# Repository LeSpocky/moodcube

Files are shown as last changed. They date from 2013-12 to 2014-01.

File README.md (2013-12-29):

MoodCube
========

What's This?
------------

With mood39 aka Starterkit from [Netz39](http://www.netz39.de/) and the
[infinity mirror cube](http://www.netz39.de/projekte/infinitiy-mirror-cube/) 
from Frank in mind I designed a mood lamp with five RGB LEDs, three
potentiometers and an ATtiny 24/44 controller.

Circuits
--------

Eagle files for both types of PCB are included. One is the base with the
microcontroller and the potentiometers. VCC is intended to be 5V,
however in the first prototype there's no voltage control circuit on
this pcb, so you have to connect a stabilized power supply.

The other one is a PCB for the LED. Current is hold constant by a simple
constant current circuit per color channel. The connection is simply one
cable per channel plus VCC and GND. uC I/O ports are directly connected
to the color lines.

Housing
-------

The housing in the prototype was 6mm plexiglass milled on a CNC machine.
Holding it together was forgotten in design, but the OpenSCAD files are
added here anyway. Simply glueing them is one solution. You could also
make a base plate or anything else.

LED-PCB Mount
-------------

For the prototype I used a frame construction printed with a 3D printer
and lots of hot melt glue. However this was far from optimal and should
not repeated! Please think up a better solution and let me know!

Part List
---------
/tbd/

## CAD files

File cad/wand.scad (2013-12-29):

// outer wall made from plexiglass to form a cube 150mm×150mm

module wand() {
	linear_extrude( height = 6 ) 
			polygon( points = [ [6,0], [6,25], [0,25], [0,50], [6,50], [6,75], 
				[0,75], [0,100], [6,100], [6,125], [0,125], [0,150], [144,150], 
				[144,125], [150,125], [150,100], [144,100], [144,75], [150,75], 
				[150,50], [144,50], [144,25], [150,25], [150,0] ] );
}

module wand_1() {
	difference() {
		wand();
		translate( [ 65, 5.9, 3 ] ) cube( size = [ 20, 3.2, 4 ] );
		translate ( [ 75, 25, 3 ] ) cylinder( h = 10, r = 4.5, center = true );
	}
}

module wand_2() {
	difference() {
		wand();
		translate( [ 65, 5.9, 3 ] ) cube( size = [ 20, 3.2, 4 ] );
		translate( [ 50, 25, 3 ] ) cylinder( h = 10, r = 5.5, center = true );
		translate( [ 100, 25, 3 ] ) cylinder( h = 10, r = 10.5, center = true );
	}
}

projection( cut = true ) 
	translate ( [ 0, 0, -4 ] ) {
		wand_2();
		translate( [ 155, 0, 0 ] ) wand_1();
		translate( [ 155, 152, 0 ] ) wand_1();
		translate( [ 0, 152, 0 ] ) wand_1();
	}

/* vim: set noet sts=0 ts=4 sw=4 sr: */

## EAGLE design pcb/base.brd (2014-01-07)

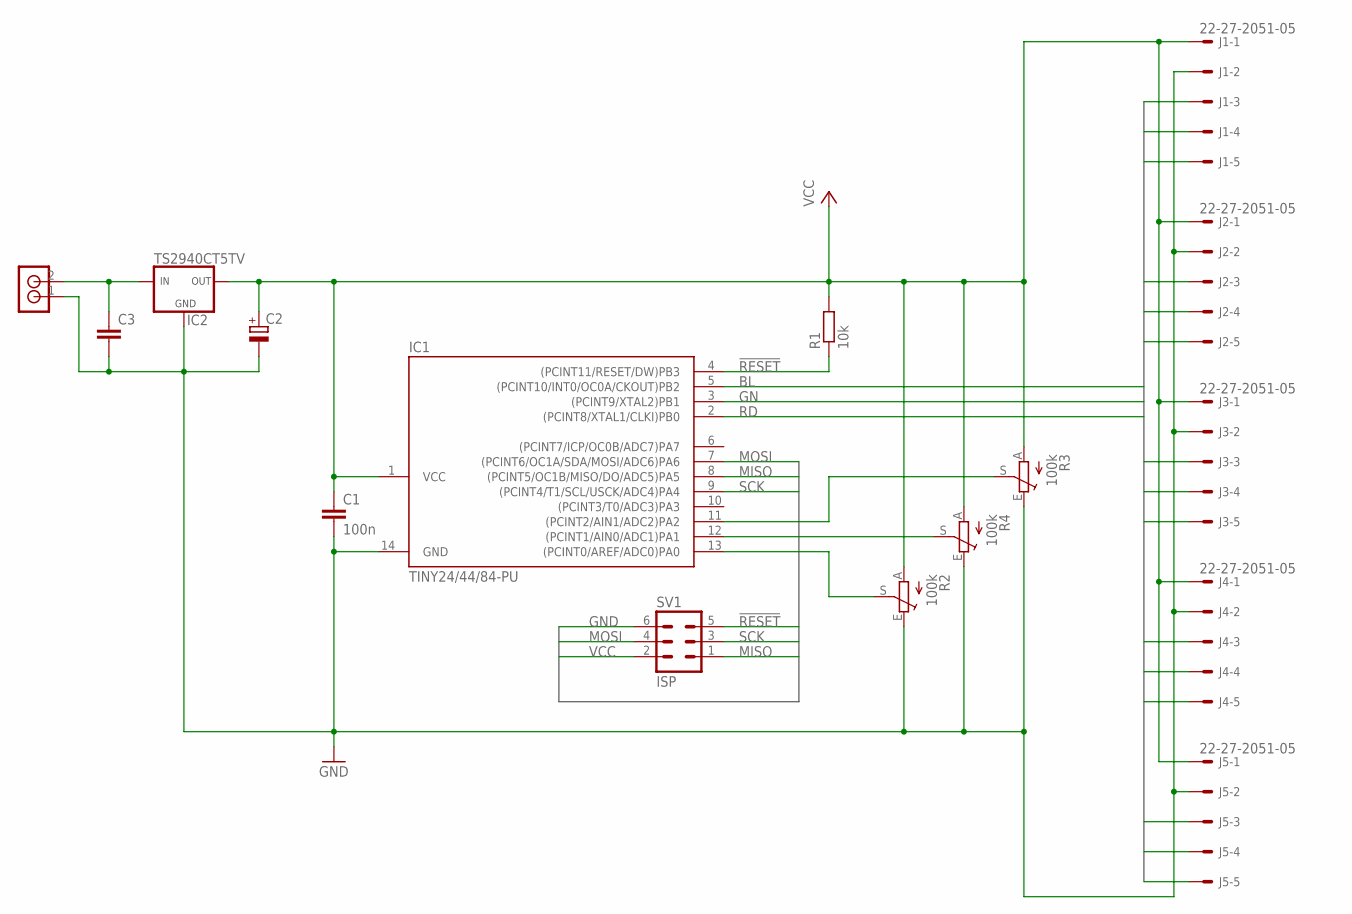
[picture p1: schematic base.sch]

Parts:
C1: 100n; C0805
C2: CPOL-EUE2.5-7; E2,5-7
C3: C-EU025-025X050; C025-025X050
IC1: TINY24/44/84-PU; DIL14
IC2: TS2940CT5TV; TO220V
J1, J2, J3, J4, J5: 22-27-2051-05; 6410-05
R1: 10k; R0805
R2, R3, R4: 100k; CIP20C-6MM
SV1: ISP; ML6
U$9: RIACON_101_2

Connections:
!RESET: IC1.4 ((PCINT11/RESET/DW)PB3), R1.1, SV1.5
BL: IC1.5 ((PCINT10/INT0/OC0A/CKOUT)PB2), J1.5, J2.5, J3.5, J4.5, J5.5
GN: IC1.3 ((PCINT9/XTAL2)PB1), J1.4, J2.4, J3.4, J4.4, J5.4
GND: C1.2, C2.-, C3.2, IC1.14 (GND), IC2.2 (GND), J1.2, J2.2, J3.2, J4.2, J5.2, R2.E, R3.E, R4.E, SV1.6, U$9.1
MISO: IC1.8 ((PCINT5/OC1B/MISO/DO/ADC5)PA5), SV1.1
MOSI: IC1.7 ((PCINT6/OC1A/SDA/MOSI/ADC6)PA6), SV1.4
unnamed: IC1.13 ((PCINT0/AREF/ADC0)PA0), R2.S
unnamed: IC1.12 ((PCINT1/AIN0/ADC1)PA1), R4.S
unnamed: IC1.11 ((PCINT2/AIN1/ADC2)PA2), R3.S
unnamed: C3.1, IC2.1 (IN), U$9.2
RD: IC1.2 ((PCINT8/XTAL1/CLKI)PB0), J1.3, J2.3, J3.3, J4.3, J5.3
SCK: IC1.9 ((PCINT4/T1/SCL/USCK/ADC4)PA4), SV1.3
VCC: C1.1, C2.+, IC1.1 (VCC), IC2.3 (OUT), J1.1, J2.1, J3.1, J4.1, J5.1, R1.2, R2.A, R3.A, R4.A, SV1.2

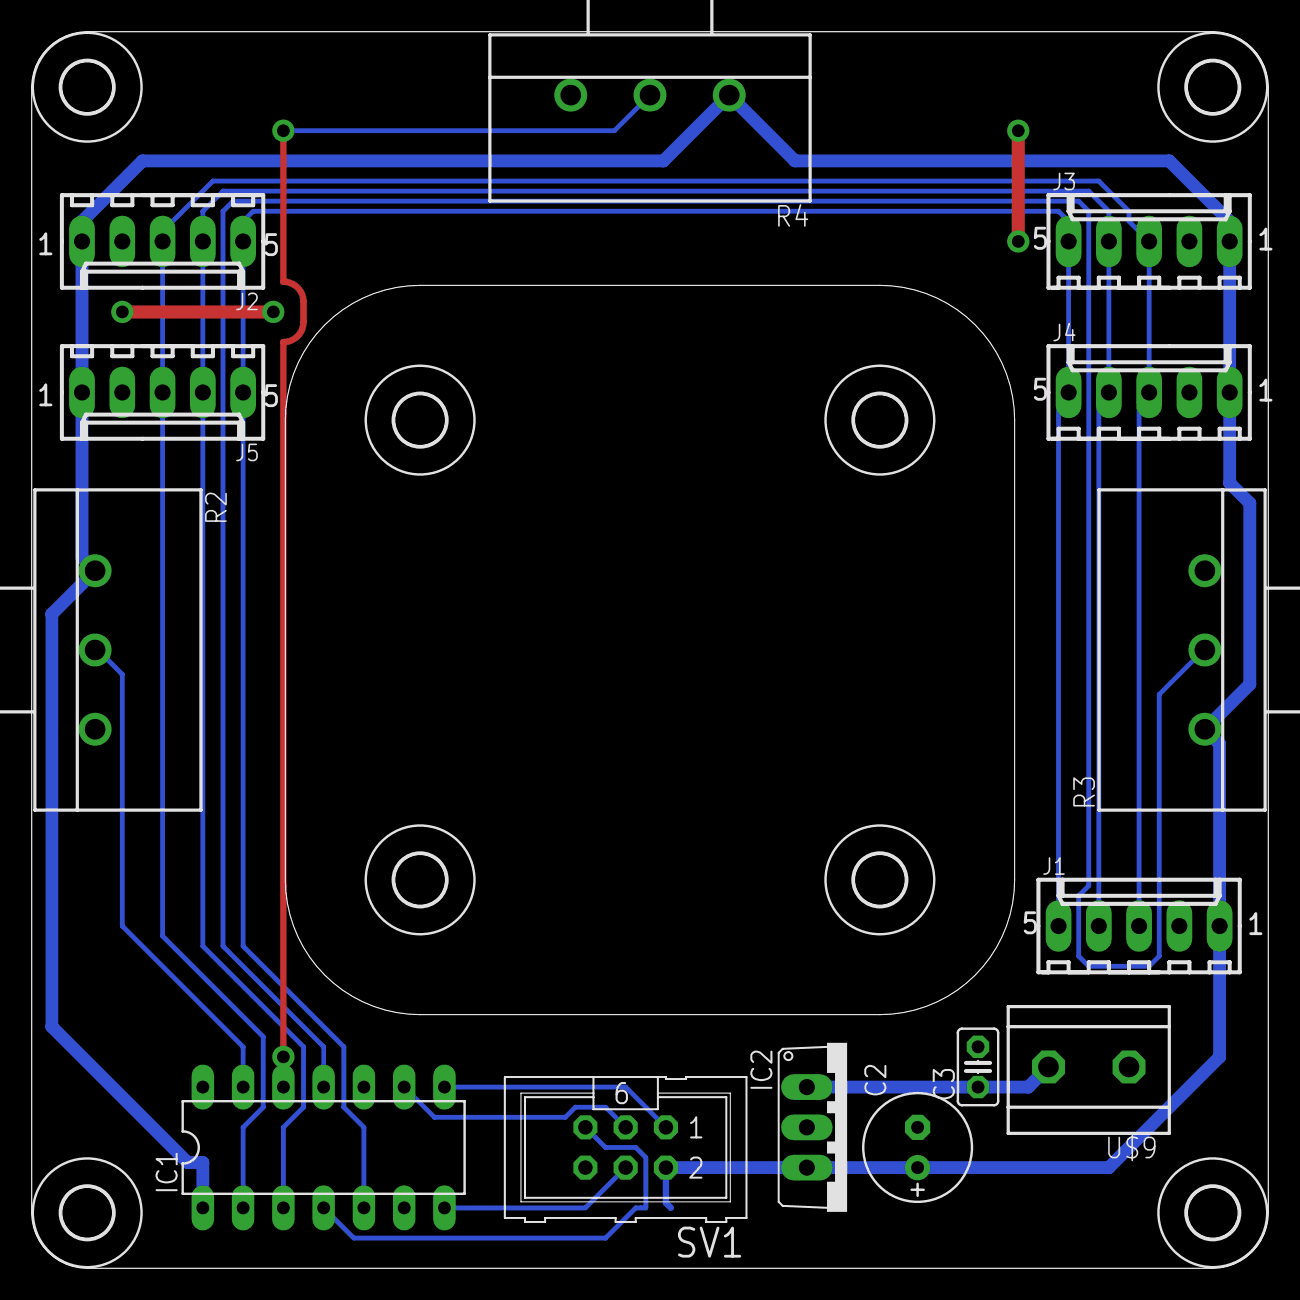
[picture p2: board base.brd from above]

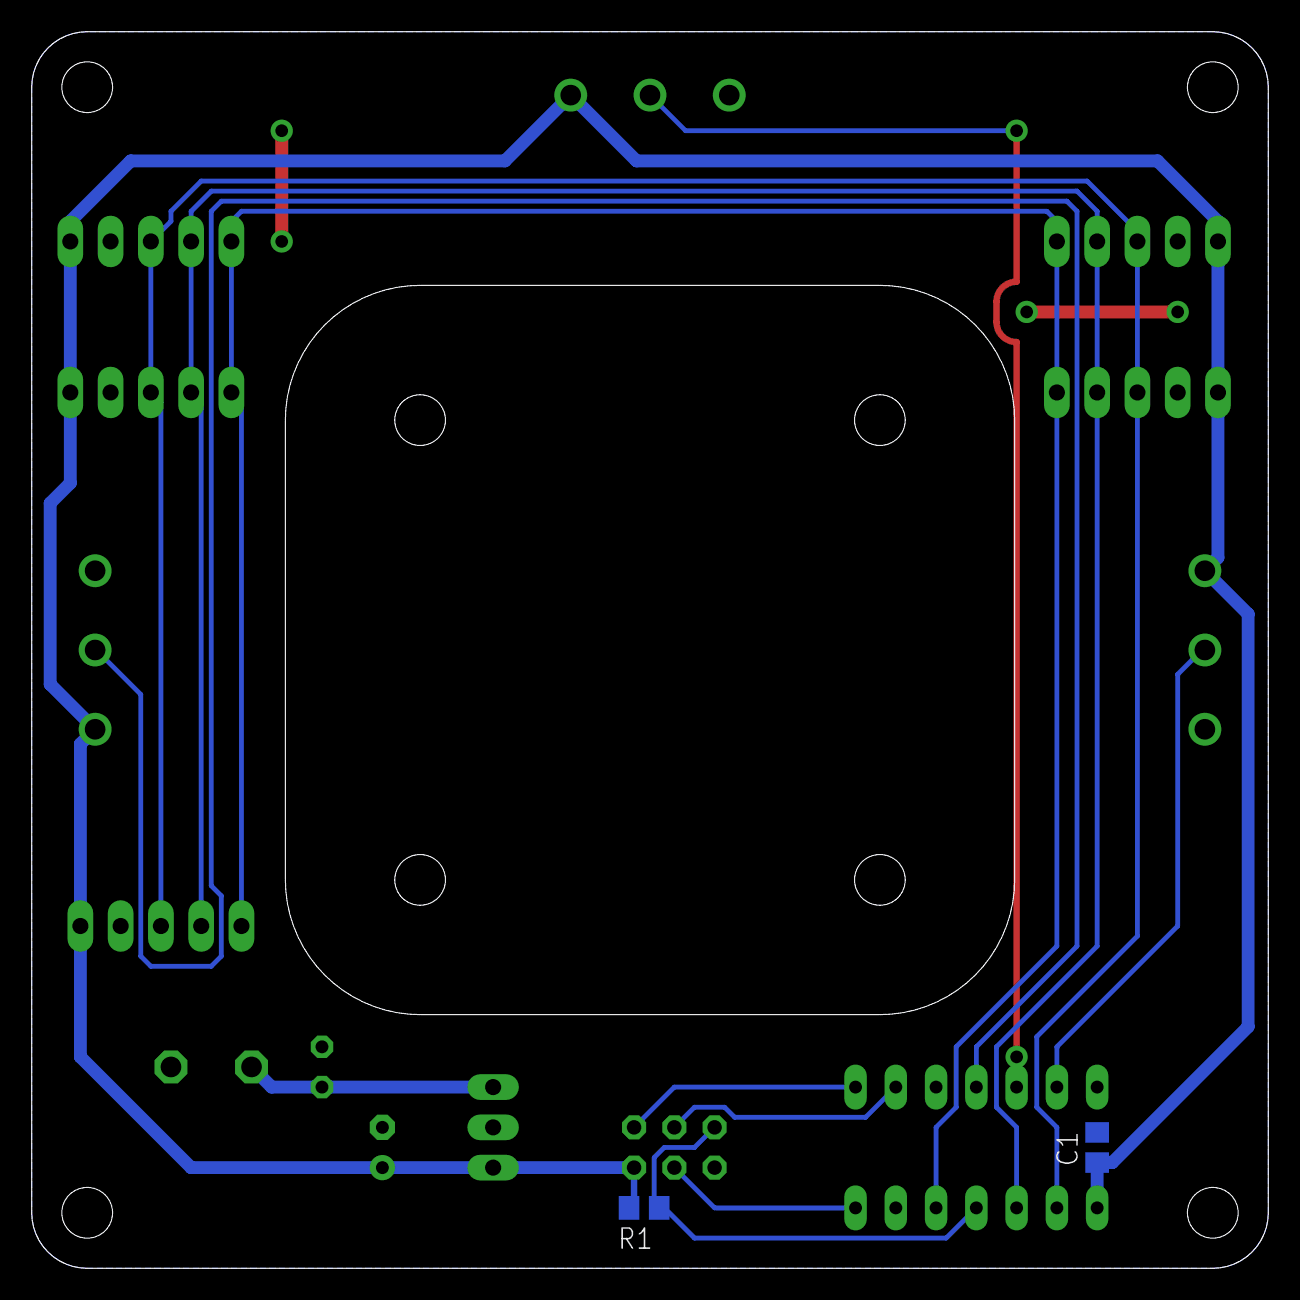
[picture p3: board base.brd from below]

Board: 2 copper layers, 78.0 x 78.0 mm, 24 parts (2 on the bottom side), 13 nets.

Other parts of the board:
U$1, U$2, U$3, U$4, U$5, U$6, U$7, U$8: 3,2

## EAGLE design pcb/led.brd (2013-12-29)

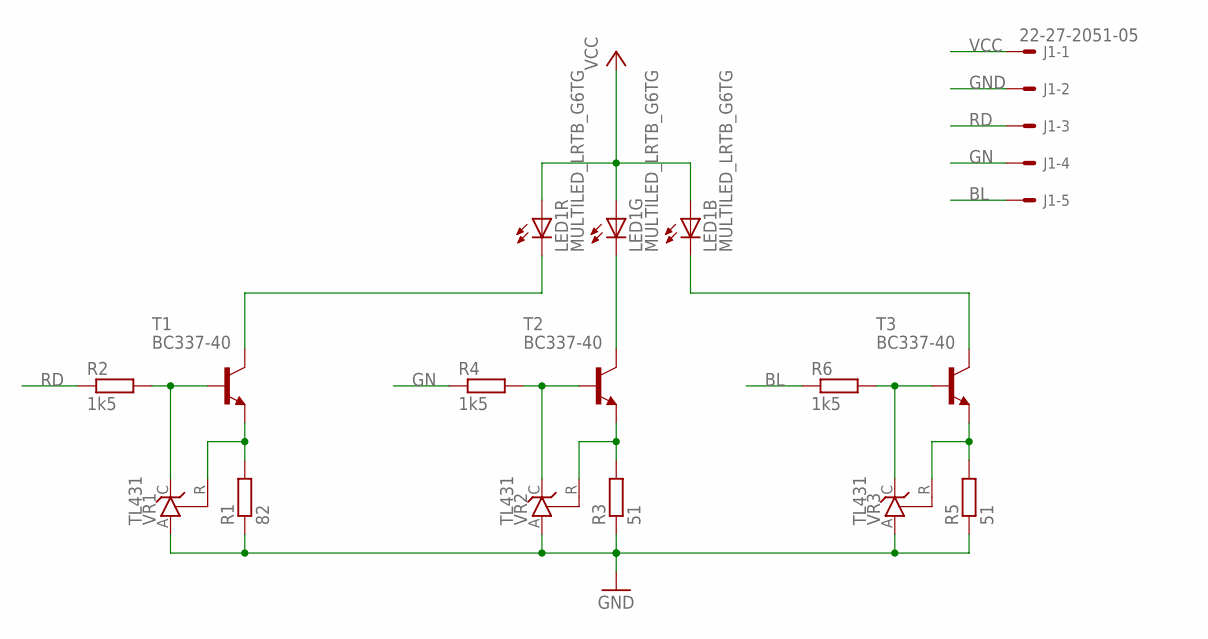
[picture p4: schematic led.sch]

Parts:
J1: 22-27-2051-05; 6410-05
LED1: MULTILED_LRTB_G6TG; P-LCC-6_TOPLED
R1: 82; 0207/7
R2, R6: 1k5; R0805
R3, R5: 51; 0207/7
R4: 1k5; 0207/10
T1, T2, T3: BC337-40; TO92-CBE
VR1, VR2, VR3: TL431; TO92-CLP

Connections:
BL: J1.5, R6.1
GN: J1.4, R4.1
GND: J1.2, R1.1, R3.1, R5.1, VR1.A, VR2.A, VR3.A
unnamed: R1.2, T1.E, VR1.R
unnamed: R3.2, T2.E, VR2.R
unnamed: R2.2, T1.B, VR1.C
unnamed: R4.2, T2.B, VR2.C
unnamed: LED1.C1 (C), T1.C
unnamed: LED1.C2 (C), T2.C
RD: J1.3, R2.1
T3_B-C: R6.2, T3.B, VR3.C
T3_C: LED1.C3 (C), T3.C
T3_E-R: R5.2, T3.E, VR3.R
VCC: J1.1, LED1.A1 (A), LED1.A2 (A), LED1.A3 (A)

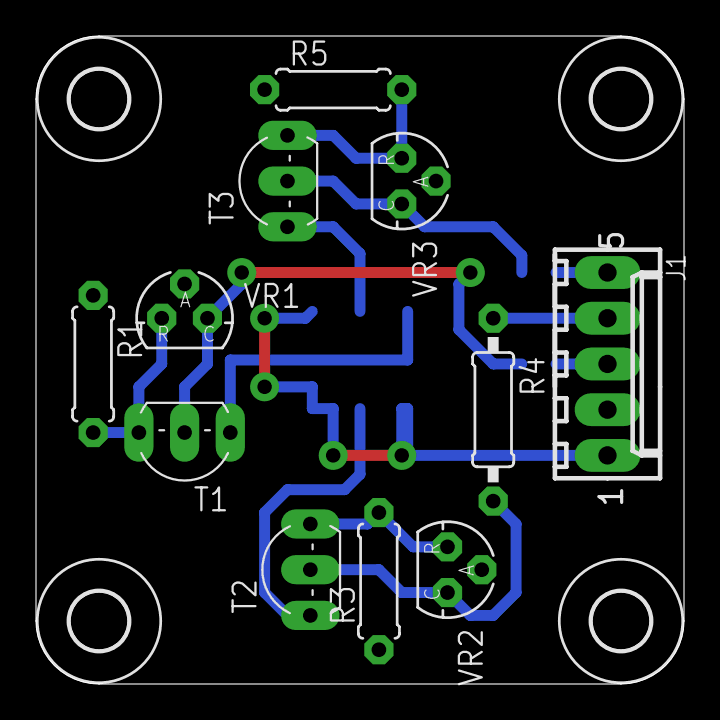
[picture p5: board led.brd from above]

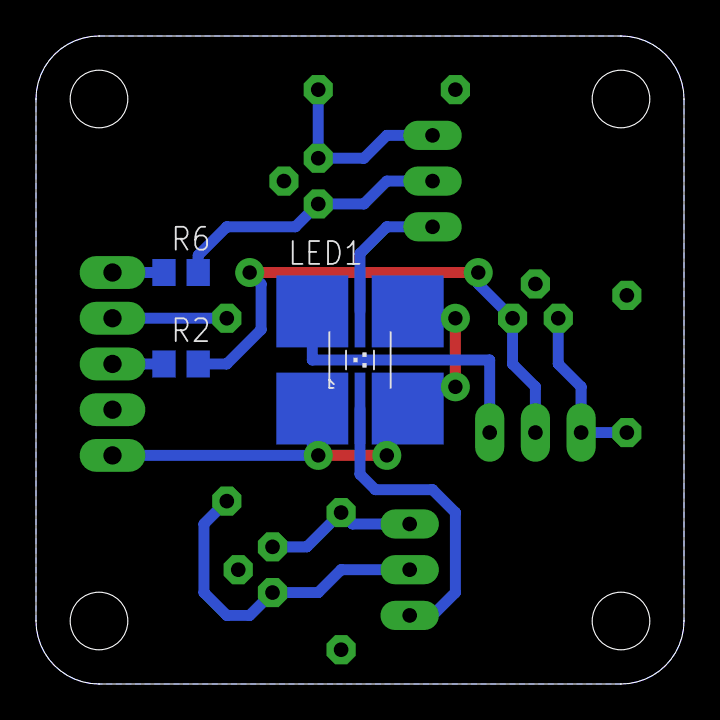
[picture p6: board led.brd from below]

Board: 2 copper layers, 36.0 x 36.0 mm, 18 parts (3 on the bottom side), 14 nets.

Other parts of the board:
U$1, U$2, U$3, U$4: 3,2

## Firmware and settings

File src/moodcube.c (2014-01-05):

#include <stdbool.h>
#include <stdint.h>

#include <avr/io.h>
#include <avr/interrupt.h>
#include <util/delay.h>

#include "gamma.h"
#include "hsv2rgb.h"

#define DIR_RD          (1 << DDB0)
#define DIR_GN          (1 << DDB1)
#define DIR_BL          (1 << DDB2)
#define PORT_RD         (1 << PORTB0)
#define PORT_GN         (1 << PORTB1)
#define PORT_BL         (1 << PORTB2)
#define PORT_MASK       (PORT_RD | PORT_GN | PORT_BL)
#define INVERTED_LED    false

#define MASK_ADPS       0x07    /*  ADPS2:ADPS0 in ADCSRA   */
#define MASK_ADTS       0x07    /*  ADTS2:ADTS0 in ADCSRB           */
#define MASK_REFS       0xC0    /*  REFS1,REFS0 in ADMUX    */
#define MASK_MUX        0x3F    /*  MUX5:MUX0 in ADMUX      */

/*  globals */
volatile uint8_t adc_result[3];
volatile uint16_t comp_buf_R, comp_buf_G, comp_buf_B;

/*  declaration */
void init( void );

/*  ISR */
ISR(TIM0_OVF_vect) {
    static uint8_t  pin_level = ( INVERTED_LED ? 0 : PORT_MASK );
    static uint8_t  led_status = 0;
    static uint16_t comp_R, comp_G, comp_B;
    static uint16_t soft_cnt_R = 0x01FF;
    static uint16_t soft_cnt_G = 0x01FF - 170;
    static uint16_t soft_cnt_B = 0x01FF - 340;

    /*  set new pin level first for low jitter and do calculation
     *  afterwards  */
    PORTB = pin_level;

    /*  increment counter and if overflow update compare value from
     *  main loop buffer and set LED on */
    soft_cnt_R++;
    soft_cnt_R &= 0x01FF;
    if ( soft_cnt_R == 0 ) {
        comp_R = comp_buf_R;
        led_status |= PORT_RD;
    }
    soft_cnt_G++;
    soft_cnt_G &= 0x01FF;
    if ( soft_cnt_G == 0 ) {
        comp_G = comp_buf_G;
        led_status |= PORT_GN;
    }
    soft_cnt_B++;
    soft_cnt_B &= 0x01FF;
    if ( soft_cnt_B == 0 ) {
        comp_B = comp_buf_B;
        led_status |= PORT_BL;
    }

    /*  on compare match set LED off (written to port on next
     *  interrupt)  */
    if ( comp_R == soft_cnt_R ) {
        led_status &= ~PORT_RD;
    }
    if ( comp_G == soft_cnt_G ) {
        led_status &= ~PORT_GN;
    }
    if ( comp_B == soft_cnt_B ) {
        led_status &= ~PORT_BL;
    }

    pin_level = ( INVERTED_LED ? ~led_status : led_status ) & PORT_MASK;
}

ISR(ADC_vect) {
    static uint8_t adc_ch = 0;

    /*  get */
    adc_result[adc_ch] = ADCH;

    /*  set next channel    */
    if ( ++adc_ch == 3 ) adc_ch = 0;
    ADMUX = (ADMUX & ~MASK_MUX) | (adc_ch & MASK_MUX);
}

/*  main    */
int main( void ) {
    uint8_t h, s, v, r, g, b;

    init();
    init8();

    /*  main loop   */
    while ( 1 ) {
        /*  seems like potis are wired inverted */
        h = 255 - adc_result[0];
        s = 255 - adc_result[1];
        v = 255 - adc_result[2];

        rgb( h, s, v, &r, &g, &b );

        comp_buf_R = pgm_read_word( &(gammatbl[r]) );
        comp_buf_G = pgm_read_word( &(gammatbl[g]) );
        comp_buf_B = pgm_read_word( &(gammatbl[b]) );
    }

    return 0;
}

/*  implementation  */
void init( void ) {
    /*  start values for PWM    */
    comp_buf_R = 0;
    comp_buf_G = 0;
    comp_buf_B = 0;

    /*  start results for adc    */
    adc_result[0] = 0;
    adc_result[1] = 0;
    adc_result[2] = 0;

    /*  disable interrupts and ADC  */
    cli();
    ADCSRA &= ~(1 << ADEN);
    PRR &= ~(1 << PRADC);   /*  disable power reduction for ADC after
                                disabling ADC itself    */

    /*  set clock   */
    CLKPR = (1 << CLKPCE);  /*  enable clock prescaler update       */
    CLKPR = 0;              /*  set clock to maximum                */

    /*  set port pins to output and value 0 */
    DDRB = DIR_RD | DIR_GN | DIR_BL;
    PORTB = 0;

    /*  timer init  */
    TIFR0 &= ~(1 << TOV0);   /*  clear timer0 overflow interrupt flag    */
    TIMSK0 |= (1 << TOIE0);  /*  enable timer0 overflow interrupt        */

    /*  start timer0 by setting last 3 bits in timer0 control register B
     *  to any clock source */
    TCCR0B = (TCCR0B & 0xF8) | (0x01 & 0x07);

    /*  use VCC as voltage reference (disconnected from PB0/AREF)   */
    ADMUX = (ADMUX & ~MASK_REFS) | 0;   /*  REFS2:REFS0 all cleared */

    /*  put conversion result left bounded in ADCH/ADCL, so we only need
     *  to fetch ADCH for an 8-bit result   */
    ADCSRB |= (1 << ADLAR);

    /*  set which ADC pin is used, start with 0   */
    ADMUX = (ADMUX & ~MASK_MUX) | (0 & MASK_MUX);

    /*  set prescaler in a way the ADC clock gets between 50khZ and
     *  200 kHz. using a prescaler of 128 here yields a value in this
     *  interval for both 8MHz and 16MHz clock. */
    /*  TODO    check this for default 1 MHz or make dependent on cpu
     *          clock speed!    */
    ADCSRA = (ADCSRA & ~MASK_ADPS) | (0x07 & MASK_ADPS);

    /*  use ADC free running mode   */
    ADCSRA |= (1 << ADATE);
    ADCSRB = (ADCSRB & ~MASK_ADTS) | 0; /*  ADTS2:ADTS0 all cleared */

    /*  enable interrupts and ADC   */
    ADCSRA |= (1 << ADEN);
    ADCSRA |= (1 << ADIE);
    sei();

    /*  start ADC conversion    */
    ADCSRA |= (1 << ADSC);
}

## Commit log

2013-12-23 copied timer and pwm stuff from avr101
2013-12-23 add ADC stuff and adapt to attiny24 and 3 channels
2013-12-29 added pcb files, one cad file, and added some stuff to readme
    [base.brd, base.sch, led.brd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]
2014-01-05 use a 9 bit PWM and a 256 step lookup table
2014-01-06 add voltage regulator and other clamp
    [base.brd, base.sch]
2014-01-07 route voltage regulator
    [base.brd, base.sch]
